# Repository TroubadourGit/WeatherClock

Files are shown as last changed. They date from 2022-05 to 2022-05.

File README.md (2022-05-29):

# 天气闹钟 (WeatherClock)

| 版本 | 修改日期  | 修改人 | 变更 |
| ---- | --- | --- | ---- |
| V1.0 | 2022.5.29 | Troubadour | |

---

## 主要功能

  1. 用户可以进行自行配网；
  2. WeatherClock 连上网络后会自动向互联网获取信息，获取的信息是：时间和天气预报；
  3. WeatherClock 带有一个显示屏， 显示界面共有三个：时间、当前天气、后天的天气预报，每5s切换一次界面。

---

## 使用说明

  1. 开机：拨动 WeatherClock 的开关即可开机， 开机亮蓝色指示灯。
  2. 配网：开机后第一件事情就是配网，刚开机时 WeatherClock 会自己开启一个wifi热点，用手机连上后会自动跳转到浏览器配网界面，在该界面为 WeatherClock 配网。配完网之后，等待 WeatherClock 加载即可。
  3. 充电：WeatherClock 自带一块800mh的锂电池，理论待机30小时以上。充电只需要手机充电器；注意，充电接口为Type-C接口。充电时亮起红色指示灯说明正在充电，充满电后红色指示灯熄灭。

***

## 文档说明

1. PCB+SCH：存放WeatherClock的PCB和原理图。
2. code：存放WeatherClock的代码。
3. 3DFile：存放3D外壳文件。
4. Other：存放开发以来一共购入的材料的excel文件。

---

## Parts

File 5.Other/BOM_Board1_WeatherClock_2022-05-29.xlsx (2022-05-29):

No. | Quantity | Device | Designator | Footprint | Supplier Part
1 | 1 | 0.1uF | C1 | C0805
2 | 1 | 0.1uF_C0805 | C2 | C0805
3 | 1 | 10uF | C3 | C0805
4 | 3 | 10uF_C0805 | C4,C5,C9 | C0805
5 | 1 | 68pF | C6 | C0805
6 | 1 | 22uF | C7 | C0805
7 | 1 | 22uF_C0805 | C8 | C0805
8 | 1 | ZH1.5_2P | J1 | CONN-TH_B2B-ZR-3.4-LF-SN | C163033
9 | 1 | L1008 | L1 | L0402 | C560042
10 | 1 | 红灯 | LED1 | LED0805_RED | C72037
11 | 1 | 蓝灯 | LED2 | LED0805_BLUE | C108412
12 | 1 | OLED-0.96-12864-IIC | M1 | OLED-0.96-12864-IIC_4PIN | ZJY096I0400WG11
13 | 1 | S8050 | Q1 | SOT-23-3_L2.9-W1.3-P1.90-LS2.4-BR | C2926165
14 | 1 | S8050_SOT-23-3_L2.9-W1.3-P1.90-LS2.4-BR | Q2 | SOT-23-3_L2.9-W1.3-P1.90-LS2.4-BR | C2926165
15 | 3 | 10k_R0805 | R1,R11,R12 | R0805
16 | 1 | 10k | R2 | R0805
17 | 1 | 4.7k | R3 | R0805
18 | 1 | 4.7k_R0805 | R4 | R0805
19 | 1 | 2k | R5 | R0805
20 | 1 | 1k | R6 | R0805
21 | 1 | 820k | R7 | R0805
22 | 1 | 143k | R8 | R0805
23 | 1 | 750k | R9 | R0805
24 | 1 | 1K_R0805 | R10 | R0805
25 | 1 | SK12D07VG6 | SW1 | SW-TH_SK12D07VG6 | C2681575
26 | 1 | ESP-01S_C503582 | U1 | WIFIM-TH_8P-L24.7-W14.4-P2.54 | C503582
27 | 1 | CH340C | U2 | SOP-16_L10.0-W3.9-P1.27-LS6.0-BL | C84681
28 | 1 | MP2155GQ-Z | U3 | QFN-10_L3.0-W3.0-P0.50-LS3.0-BL-EP | C110397
29 | 1 | PJ4054 | U4 | SOT-23-5_L3.0-W1.7-P0.95-LS2.8-TL | C440262
30 | 1 | KH-TYPE-C-16P | USB1 | USB-C-SMD_KH-TYPE-C-16P | C709357

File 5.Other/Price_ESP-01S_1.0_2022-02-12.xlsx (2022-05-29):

ID | 名称 | 标识符 | 封装 | 数量 | 单价 | 运费 | 小计 | 渠道 | 备注
 | V1.0 购入以下
1 | 0.1uF | C1,C2 | C0805 | 100 | 0.02 | 0 | 2 | 淘宝 | 深圳市裕泓科技有限公司
2 | 10uF | C3,C5 | C0805 | 100 | 0.02 | 0 | 2 | 淘宝 | 深圳市裕泓科技有限公司
3 | 红灯 | LED1 | LED0805_RED | 100 | 0.02 | 0 | 2 | 淘宝 | 深圳市裕泓科技有限公司
4 | 蓝灯 | LED2 | LED0805_BLUE | 100 | 0.02 | 0 | 2 | 淘宝 | 深圳市裕泓科技有限公司
5 | 10k | R1,R2 | R0805 | 100 | 0.02 | 0 | 2 | 淘宝 | 深圳市裕泓科技有限公司
6 | 4.7k | R3,R4 | R0805 | 100 | 0.02 | 0 | 2 | 淘宝 | 深圳市裕泓科技有限公司
7 | 1.2k | R5 | R0805 | 100 | 0.02 | 0 | 2 | 淘宝 | 深圳市裕泓科技有限公司
8 | 1k | R6,R8 | R0805 | 100 | 0.02 | 0 | 2 | 淘宝 | 深圳市裕泓科技有限公司
9 | OLED-0.96-12864-IIC | M1 | OLED-0.96-12864-IIC_4PIN | 3 | 10.8 | 0 | 32.4 | 淘宝 | 信泰微电子
10 | PJ4054 | U4 | SOT-23-5_L3.0-W1.7-P0.95-LS2.8-TL | 5 | 0.36 | 1.8 | 3.6 | 淘宝 | 酷米仕科技官方店
11 | ESP-01S_C503582 | U1 | WIFIM-TH_8P-L24.7-W14.4-P2.54 | 3 | 5.033333333 | 5 | 20.1 | 淘宝 | 深圳市轩特佳电子
12 | CH340C | U2 | SOP-16_L10.0-W3.9-P1.27-LS6.0-BL | 5 | 3.12 | 0 | 15.6 | 淘宝 | 深圳市优信电子
13 | 3.7V锂电池包 | BAT1 | 730mh-603040_ZH1.5-2P | 2 | 9.705 | 0 | 19.41 | 淘宝 | 深圳市绍能电子
14 | ZH1.5_2P | J1 | CONN-TH_B2B-ZR-3.4-LF-SN | 10 | 0.349 | 1.75 | 5.24 | 立创商城 | C163033
15 | SK12D07VG4 | SW1 | SW-TH_SK12D07VG4 | 50 | 0.12 | 1.75 | 7.75 | 立创商城 | C393937
16 | AMS1117-3.3_C369933 | U3 | SOT-223-4_L6.5-W3.5-P2.30-LS7.0-BR | 5 | 0.552 | 1.75 | 4.51 | 立创商城 | C369933
17 | MICROXNJ | USB1 | MICRO-USB-SMD_MICROXNJ | 10 | 0.285 | 1.75 | 4.6 | 立创商城 | C404969
 |  |  |  |  |  | 小结： | 129.21
 | V1.1 购入以下
18 | 68pF | C6 | C0805 | 50 | 0.04 | 0 | 2 | 淘宝 | 欧贝顿旗舰店
19 | 22uF | C7,C8 | C0805 | 20 | 0.1 | 0 | 2 | 淘宝 | 欧贝顿旗舰店
20 | 820k | R7 | R0805 | 100 | 0.026 | 0 | 2.6 | 淘宝 | 欧贝顿旗舰店
21 | 143k | R8 | R0805 | 100 | 0.03 | 0 | 3 | 淘宝 | 欧贝顿旗舰店
22 | 750k | R9 | R0805 | 100 | 0.026 | 0 | 2.6 | 淘宝 | 欧贝顿旗舰店
23 | 470Ω | R10 | R0805 | 100 | 0.026 | 0 | 2.6 | 淘宝 | 欧贝顿旗舰店
24 | MP2155GQ-Z | U3 | QFN-10_L3.0-W3.0-P0.50-LS3.0-BL-EP | 5 | 3 | 0 | 15 | 淘宝 | 深圳市裕泓科技有限公司
25 | KH-TYPE-C-16P | USB1 | USB-C-SMD_KH-TYPE-C-16P | 10 | 0.552 | 3.5 | 9.02 | 立创商城 | C709357
26 | 3.3uH | L1 | L0805 | 10 | 0.378 | 3.5 | 7.28 | 立创商城 | C162585
 |  |  |  |  |  | 小结： | 46.1
 | V1.5 购入以下
27 | ZH1.5mm端子线 |  |  | 5 | 1 |  | 5 | 淘宝 | 深圳市优信电子
28 | 3.7V锂电池包 | BAT1 | 1500mh-103040_ZH1.5-2P | 2 | 5.95 |  | 11.9 | 淘宝 | 雅格电池
29 | S8050 | Q1 | SOT-23-3_L2.9-W1.3-P1.90-LS2.4-BR | 100 | 0.03 |  | 3 | 淘宝 | 欧贝顿旗舰店
30 | S8550 | Q1 | SOT-23-3_L2.9-W1.3-P1.90-LS2.4-BR | 100 | 0.03 |  | 3 | 淘宝 | 欧贝顿旗舰店
31 | PJ4054 | U4 | SOT-23-5_L3.0-W1.7-P0.95-LS2.8-TL | 10 | 0.36 | 1.8 | 5.4 | 淘宝 | 酷米仕科技官方店
32 | MP2155GQ-Z | U3 | QFN-10_L3.0-W3.0-P0.50-LS3.0-BL-EP | 5 | 3 | 0 | 15 | 淘宝 | 深圳市裕泓科技有限公
33 | CH340C | U2 | SOP-16_L10.0-W3.9-P1.27-LS6.0-BL | 2 | 2.8 |  | 5.6 | 淘宝 | 深圳市瑞芯拓展电子商
34 | SK12D07VG6 | SW1 | SW-TH_SK12D07VG6 | 20 | 0.1085 |  | 2.17 | 立创商城 | C2681575
35 | 2k±1% | R5 | R0805 | 200 | 0.01535 |  | 3.07 | 立创商城 | C17604
36 | ZH1.5_2P | J1 | CONN-TH_B2B-ZR-3.4-LF-SN | 20 | 0.244 |  | 4.88 | 立创商城 | C158011
37 | KH-TYPE-C-16P | USB1 | USB-C-SMD_KH-TYPE-C-16P | 10 | 0.552 |  | 5.52 | 立创商城 | C709357
38 | 3.3uH | L1 | L0805 | 10 | 0.356 |  | 3.56 | 立创商城 | C162585
39 |  |  |  |  |  | 立创运费: | 7
40 | 圆孔排母镀金 |  | 2.54-1*40P | 2 | 1.785 |  | 3.57 | 淘宝 | 晶立弘泰旗舰店
41 | 单排母 2.54mm单排母座 |  | 2.54-1*20P | 10 | 0.278 |  | 2.78 | 淘宝 | WXRKDZ电子旗舰店
42 | 单排母 2.54mm单排母座 |  | 2.54-1*10P | 20 | 0.11 |  | 2.2 | 淘宝 | WXRKDZ电子旗舰店
43 | 单排母 2.54mm单排母座 |  | 2.54-1*4P | 20 | 0.1375 |  | 2.75 | 淘宝 | WXRKDZ电子旗舰店
44 | 六角铜柱 |  | M2*5+3 | 20 | 0.097 |  | 1.94 | 淘宝 | 固万基旗舰店
45 | 304不锈钢螺母六角螺帽 |  | M2 | 50 | 0.048 |  | 2.4 | 淘宝 | 恩鼎旗舰店
46 | 不锈钢沉头自攻钉螺丝 |  | M2*5 | 100 | 0.027 |  | 2.7 | 淘宝 | 恩鼎旗舰店
47 | 不锈钢沉头自攻钉螺丝 |  | M2*8 | 150 | 0.0266 |  | 3.99 | 淘宝 | 恩鼎旗舰店
48 | 3D打印外壳第一次 |  |  | 3 | 3.853333333 | 6.01 | 17.57 | 嘉立创 | 三维猴
49 | 3D打印外壳第二次 |  |  | 4 | 3.105 | 6.01 | 18.43 | 嘉立创 | 三维猴
50 | 3D打印外壳第三次 |  |  | 4 | 4.815 | 6.02 | 25.28 | 嘉立创 | 三维猴
51 | 4D打印外壳第四次 |  |  | 4 | 4.7025 | 6.02 | 24.83 | 嘉立创 | 三维猴
 |  |  |  |  |  | 小结： | 183.54
 |  |  |  |  |  | 总价： | 358.85

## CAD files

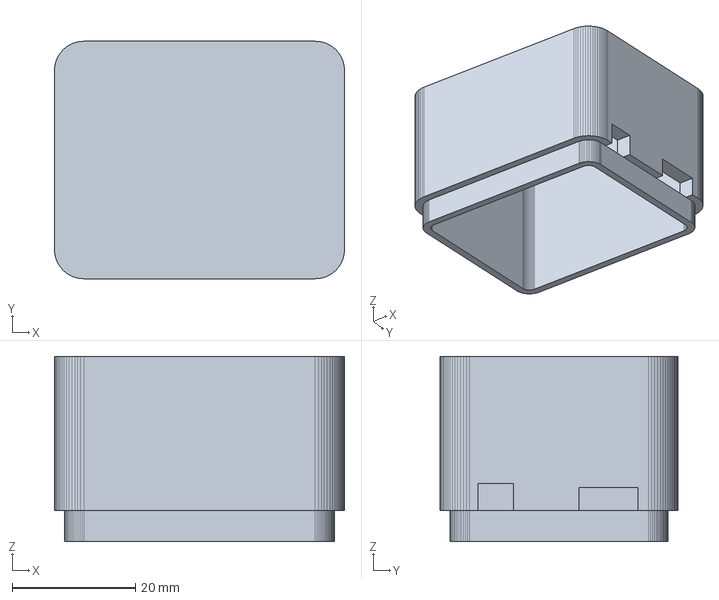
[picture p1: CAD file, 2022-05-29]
3.3DFile/3DShell_PCB_ESP-01S_T.step
47.0 x 38.5 x 30.0 mm

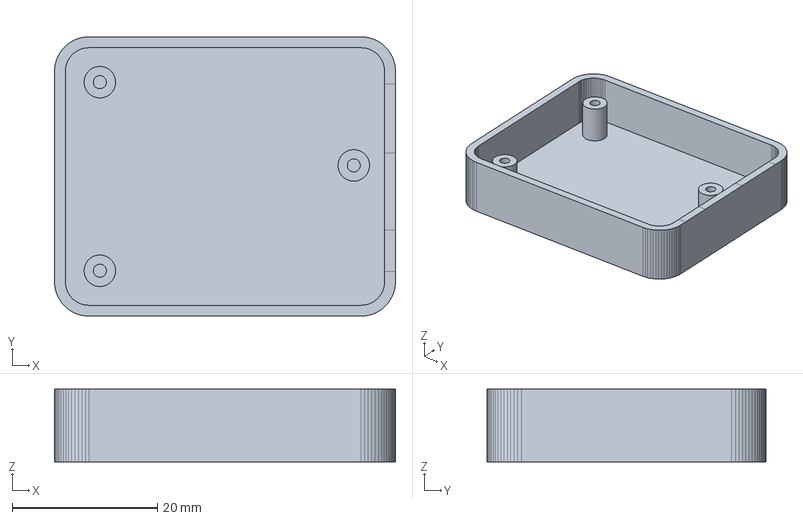
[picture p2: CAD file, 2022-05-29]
3.3DFile/3DShell_PCB_ESP-01S_B.step
47.0 x 38.5 x 10.0 mm

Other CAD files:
3.3DFile/3dshell_pcb_esp-01s_b.stl
3.3DFile/3dshell_pcb_esp-01s_t.stl

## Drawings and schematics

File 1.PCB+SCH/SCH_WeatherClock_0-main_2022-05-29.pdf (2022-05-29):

电平转换 | MUC

# 自动下载电路

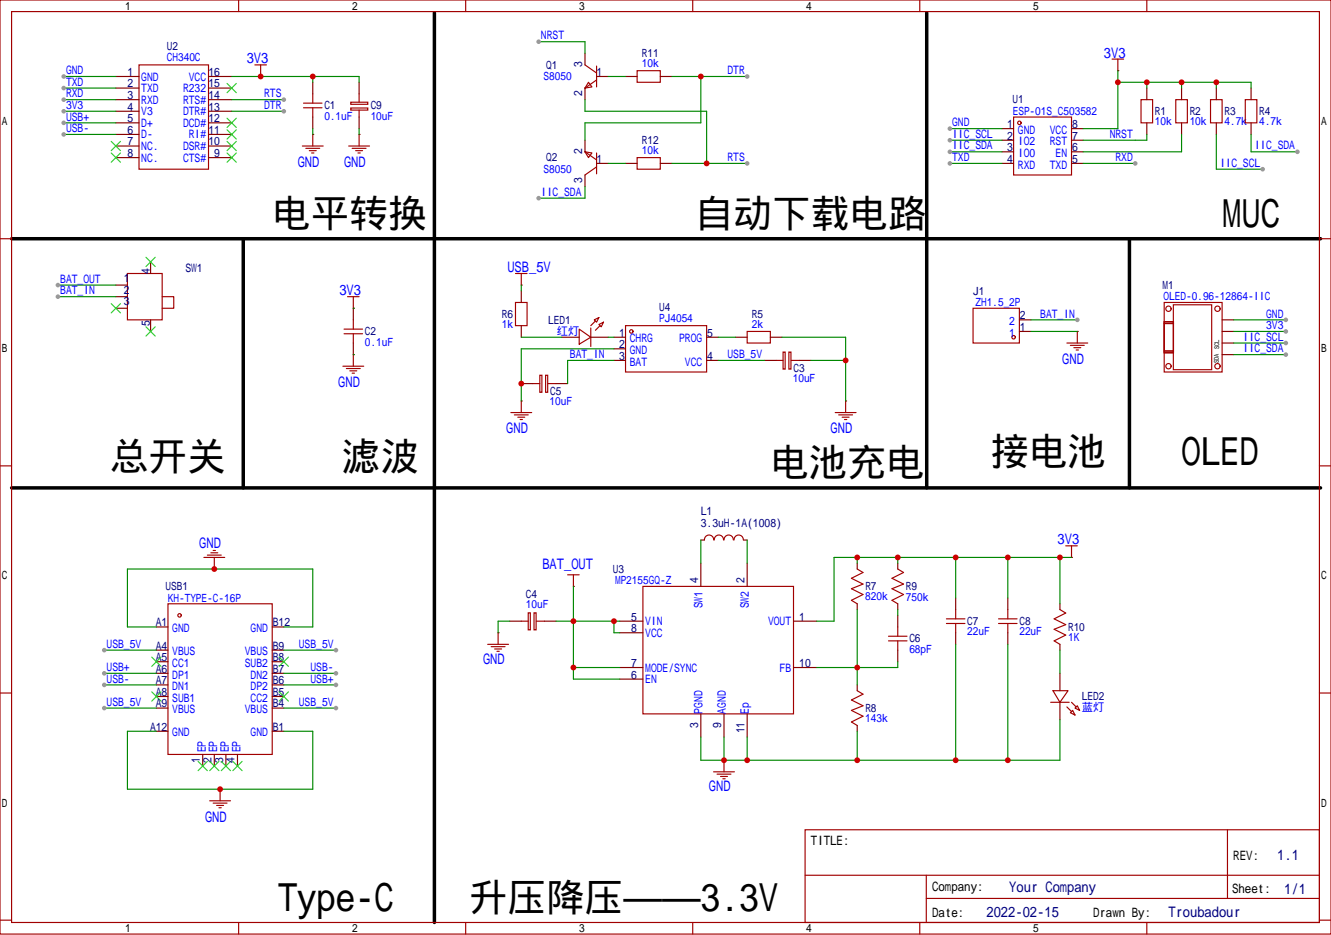
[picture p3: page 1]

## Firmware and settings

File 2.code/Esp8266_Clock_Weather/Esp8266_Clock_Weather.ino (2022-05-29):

#include <Arduino.h>
#include <ESP8266WiFi.h>
#include <ESP8266HTTPClient.h>

#include <DNSServer.h>//密码直连将其三个库注释
#include <ESP8266WebServer.h>
#include <CustomWiFiManager.h>

#include <time.h>                       
#include <sys/time.h>                  
#include <coredecls.h>      


//#include "SH1106Wire.h"   //1.3寸用这个
#include "SSD1306Wire.h"    //0.96寸用这个
#include "OLEDDisplayUi.h"
#include "HeFeng.h"
#include "WeatherStationFonts.h"
#include "WeatherStationImages.h"

/***************************
   Begin Settings
 **************************/
/*  使用Web配网请注释本宏即可  */
// #define  WifiPassConnect

const char* WIFI_SSID = "Mr.Qin";  //填写你的WIFI名称及密码
const char* WIFI_PWD = "qin666666";

const char* BILIBILIID = "104521763";  //填写你的B站账号

//由于太多人使用我的秘钥，导致获取次数超额，所以不提供秘钥了，大家可以到https:// dev.heweather.com/获取免费的
const char* HEFENG_KEY = "243a741836da45739cd3130422ca9b55"; // 填写你的和风天气秘钥
const char* HEFENG_LOCATION = "CN101280608";  // 填写你的城市ID,可到https://where.heweather.com/index.html查询
// const char* HEFENG_LOCATION = "auto_ip";         // 自动IP定位

#define TZ              8      // 中国时区为8
#define DST_MN          0      // 默认为0

const int UPDATE_INTERVAL_SECS = 5 * 60; // 5分钟更新一次天气
const int UPDATE_CURR_INTERVAL_SECS = 2 * 59; // 2分钟更新一次粉丝数

const int I2C_DISPLAY_ADDRESS = 0x3c;  //I2c地址默认
#if defined(ESP8266)
const int SDA_PIN = 0;  //引脚连接
const int SDC_PIN = 2;  //
#endif


const String WDAY_NAMES[] = {"Sun", "Mon", "Tue", "Wed", "Thu", "Fri", "Sat"};  //星期
const String MONTH_NAMES[] = {"Jan", "Feb", "Mar", "Apr", "May", "Jun", "Jul", "Aug", "Sep", "Oct", "Nov", "Dec"};  //月份

// web配网页面自定义我的图标请随便使用一个图片转base64工具转换https://oktools.net/image2base64, 64*64--JPGE格式
   const char Icon[] PROGMEM = "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";

/***************************
   End Settings
 **************************/
 
//SH1106Wire     display(I2C_DISPLAY_ADDRESS, SDA_PIN, SDC_PIN);   // 1.3寸用这个
SSD1306Wire     display(I2C_DISPLAY_ADDRESS, SDA_PIN, SDC_PIN);   // 0.96寸用这个
OLEDDisplayUi   ui( &display );

HeFengCurrentData currentWeather; //实例化对象
HeFengForeData foreWeather[3];
HeFeng HeFengClient;

#define TZ_MN           ((TZ)*60)   //时间换算
#define TZ_SEC          ((TZ)*3600)
#define DST_SEC         ((DST_MN)*60)

time_t now; //实例化时间

bool readyForWeatherUpdate = false; // 天气更新标志
bool first = true;  //首次更新标志
long timeSinceLastWUpdate = 0;    //上次更新后的时间
long timeSinceLastCurrUpdate = 0;   //上次天气更新后的时间

String fans = "-1"; //粉丝数

void drawProgress(OLEDDisplay *display, int percentage, String label);   //提前声明函数
void updateData(OLEDDisplay *display);
void updateDatas(OLEDDisplay *display);
void drawDateTime(OLEDDisplay *display, OLEDDisplayUiState* state, int16_t x, int16_t y);
void drawCurrentWeather(OLEDDisplay *display, OLEDDisplayUiState* state, int16_t x, int16_t y);
void drawForecast(OLEDDisplay *display, OLEDDisplayUiState* state, int16_t x, int16_t y);
void drawForecastDetails(OLEDDisplay *display, int x, int y, int dayIndex);
void drawHeaderOverlay(OLEDDisplay *display, OLEDDisplayUiState* state);
void setReadyForWeatherUpdate();

//添加框架
//此数组保留指向所有帧的函数指针
//框架是从右向左滑动的单个视图
FrameCallback frames[] = { drawDateTime, drawCurrentWeather, drawForecast };
//页面数量
int numberOfFrames = 3;

OverlayCallback overlays[] = { drawHeaderOverlay }; //覆盖回调函数
int numberOfOverlays = 1;  //覆盖数

void setup() {
  Serial.begin(115200);
  Serial.println();
  Serial.println();

  // 屏幕初始化
  display.init();
  display.clear();
  display.display();

  display.flipScreenVertically(); //屏幕翻转
  display.setContrast(255); //屏幕亮度

#ifdef WifiPassConnect
  // 用固定密码连接，Web配网请注释
  wificonnect();
#else
  //Web配网，密码直连请注释
  webconnect();
#endif


  ui.setTargetFPS(30);  //刷新频率

  ui.setActiveSymbol(activeSymbole); //设置活动符号
  ui.setInactiveSymbol(inactiveSymbole); //设置非活动符号

  // 符号位置
  // 你可以把这个改成TOP, LEFT, BOTTOM, RIGHT
  ui.setIndicatorPosition(BOTTOM);

  // 定义第一帧在栏中的位置
  ui.setIndicatorDirection(LEFT_RIGHT);

  // 屏幕切换方向
  // 您可以更改使用的屏幕切换方向 SLIDE_LEFT, SLIDE_RIGHT, SLIDE_TOP, SLIDE_DOWN
  ui.setFrameAnimation(SLIDE_LEFT);

  ui.setFrames(frames, numberOfFrames); // 设置框架
  ui.setTimePerFrame(5000); //设置切换时间
  
  ui.setOverlays(overlays, numberOfOverlays); //设置覆盖

  // UI负责初始化显示
  ui.init();
  display.flipScreenVertically(); //屏幕反转

  configTime(TZ_SEC, DST_SEC, "ntp.ntsc.ac.cn", "ntp1.aliyun.com"); //ntp获取时间，你也可用其他"pool.ntp.org","0.cn.pool.ntp.org","1.cn.pool.ntp.org","ntp1.aliyun.com"
  delay(200);

}

void loop() {
  if (first) {  //首次加载
    updateDatas(&display);
    first = false;
  }
  if (millis() - timeSinceLastWUpdate > (1000L * UPDATE_INTERVAL_SECS)) { //屏幕刷新
    setReadyForWeatherUpdate();
    timeSinceLastWUpdate = millis();
  }
  if (millis() - timeSinceLastCurrUpdate > (1000L * UPDATE_CURR_INTERVAL_SECS)) { //粉丝数更新
    HeFengClient.fans(&currentWeather, BILIBILIID);
    fans = String(currentWeather.follower);
    timeSinceLastCurrUpdate = millis();
  }

  if (readyForWeatherUpdate && ui.getUiState()->frameState == FIXED) { //天气更新
    updateData(&display);
  }

  int remainingTimeBudget = ui.update(); //剩余时间预算

  if (remainingTimeBudget > 0) {
    //你可以在这里工作如果你低于你的时间预算。
    delay(remainingTimeBudget);
  }
  
}

#ifdef WifiPassConnect
void wificonnect() {  //WIFI密码连接，Web配网请注释
  WiFi.begin(WIFI_SSID, WIFI_PWD);
  while (WiFi.status() != WL_CONNECTED) {
    Serial.print('.');
    delay(80);
    display.clear();
    display.drawXbm(34, 0, bili_Logo_width, bili_Logo_height, bili_Logo_5);
    display.display();
    delay(80);
    display.clear();
    display.drawXbm(34, 0, bili_Logo_width, bili_Logo_height, bili_Logo_6);
    display.display();
    delay(80);
    display.clear();
    display.drawXbm(34, 0, bili_Logo_width, bili_Logo_height, bili_Logo_7);
    display.display();
    delay(80);
    display.clear();
    display.drawXbm(34, 0, bili_Logo_width, bili_Logo_height, bili_Logo_8);
    display.display();
    delay(80);
    display.clear();
    display.drawXbm(34, 0, bili_Logo_width, bili_Logo_height, bili_Logo_1);
    display.display();
    delay(80);
    display.clear();
    display.drawXbm(34, 0, bili_Logo_width, bili_Logo_height, bili_Logo_2);
    display.display();
    delay(80);
    display.clear();
    display.drawXbm(34, 0, bili_Logo_width, bili_Logo_height, bili_Logo_3);
    display.display();
    delay(80);
    display.clear();
    display.drawXbm(34, 0, bili_Logo_width, bili_Logo_height, bili_Logo_4);
    display.display();
  }
  Serial.println("");
  delay(500);
}
#else
void webconnect() {  ////Web配网，密码直连将其注释
  display.clear();
  display.drawXbm(0, 0, 128, 64, bilibili); //显示哔哩哔哩
  display.display();

  WiFiManager wifiManager;  //实例化WiFiManager
  wifiManager.setDebugOutput(false); //关闭Debug
  //wifiManager.setConnectTimeout(10); //设置超时
  wifiManager.setHeadImgBase64(FPSTR(Icon)); //设置图标
  wifiManager.setPageTitle("欢迎来到游吟诗人的WiFi配置页");  //设置页标题

  // if (!wifiManager.autoConnect("XiaoKai-IOT-Display")) {  //AP模式
  if (!wifiManager.autoConnect("Troubadour_Config")) {  //AP模式
    Serial.println("连接失败并超时");
    //重新设置并再试一次，或者让它进入深度睡眠状态
    ESP.restart();
    delay(1000);
  }
  Serial.println("connected...^_^");
  yield();
}
#endif

void drawProgress(OLEDDisplay *display, int percentage, String label) {    //绘制进度
  display->clear();
  display->setTextAlignment(TEXT_ALIGN_CENTER);
  display->setFont(ArialMT_Plain_10);
  display->drawString(64, 10, label);
  display->drawProgressBar(2, 28, 124, 10, percentage);
  display->display();
}

void updateData(OLEDDisplay *display) {  //天气更新
  HeFengClient.doUpdateCurr(&currentWeather, HEFENG_KEY, HEFENG_LOCATION);
  HeFengClient.doUpdateFore(foreWeather, HEFENG_KEY, HEFENG_LOCATION);
  readyForWeatherUpdate = false;
}

void updateDatas(OLEDDisplay *display) {  //首次天气更新
  drawProgress(display, 0, "Updating fansnumb...");
  HeFengClient.fans(&currentWeather, BILIBILIID);
  fans = String(currentWeather.follower);
  
  drawProgress(display, 33, "Updating weather...");
  HeFengClient.doUpdateCurr(&currentWeather, HEFENG_KEY, HEFENG_LOCATION);
  
  drawProgress(display, 66, "Updating forecasts...");
  HeFengClient.doUpdateFore(foreWeather, HEFENG_KEY, HEFENG_LOCATION);
  
  readyForWeatherUpdate = false;
  drawProgress(display, 100, "Done...");
  delay(200);
  
}

void drawDateTime(OLEDDisplay *display, OLEDDisplayUiState* state, int16_t x, int16_t y) {  //显示时间
  now = time(nullptr);
  struct tm* timeInfo;
  timeInfo = localtime(&now);
  char buff[16];

  display->setTextAlignment(TEXT_ALIGN_CENTER);
  display->setFont(ArialMT_Plain_16);
  String date = WDAY_NAMES[timeInfo->tm_wday];

  sprintf_P(buff, PSTR("%04d-%02d-%02d  %s"), timeInfo->tm_year + 1900, timeInfo->tm_mon + 1, timeInfo->tm_mday, WDAY_NAMES[timeInfo->tm_wday].c_str());
  display->drawString(64 + x, 5 + y, String(buff));
  display->setFont(ArialMT_Plain_24);

  sprintf_P(buff, PSTR("%02d:%02d:%02d"), timeInfo->tm_hour, timeInfo->tm_min, timeInfo->tm_sec);
  display->drawString(64 + x, 22 + y, String(buff));
  display->setTextAlignment(TEXT_ALIGN_LEFT);
}

void drawCurrentWeather(OLEDDisplay *display, OLEDDisplayUiState* state, int16_t x, int16_t y) {  //显示天气
  display->setFont(ArialMT_Plain_10);
  display->setTextAlignment(TEXT_ALIGN_CENTER);
  display->drawString(64 + x, 38 + y, currentWeather.cond_txt + "    |   Wind: " + currentWeather.wind_sc + "  ");

  display->setFont(ArialMT_Plain_24);
  display->setTextAlignment(TEXT_ALIGN_LEFT);
  String temp = currentWeather.tmp + "°C" ;
  display->drawString(60 + x, 3 + y, temp);
  display->setFont(ArialMT_Plain_10);
  display->drawString(62 + x, 26 + y, currentWeather.fl + "°C | " + currentWeather.hum + "%");
  display->setFont(Meteocons_Plain_36);
  display->setTextAlignment(TEXT_ALIGN_CENTER);
  display->drawString(32 + x, 0 + y, currentWeather.iconMeteoCon);
}

void drawForecast(OLEDDisplay *display, OLEDDisplayUiState* state, int16_t x, int16_t y) {  //天气预报
  drawForecastDetails(display, x, y, 0);
  drawForecastDetails(display, x + 44, y, 1);
  drawForecastDetails(display, x + 88, y, 2);
}

void drawForecastDetails(OLEDDisplay *display, int x, int y, int dayIndex) {  //天气预报

  display->setTextAlignment(TEXT_ALIGN_CENTER);
  display->setFont(ArialMT_Plain_10);
  display->drawString(x + 20, y, foreWeather[dayIndex].datestr);
  display->setFont(Meteocons_Plain_21);
  display->drawString(x + 20, y + 12, foreWeather[dayIndex].iconMeteoCon);

  String temp = foreWeather[dayIndex].tmp_max + " | " + foreWeather[dayIndex].tmp_min;
  display->setFont(ArialMT_Plain_10);
  display->drawString(x + 20, y + 34, temp);
  display->setTextAlignment(TEXT_ALIGN_LEFT);
}

void drawHeaderOverlay(OLEDDisplay *display, OLEDDisplayUiState* state) {   //绘图页眉覆盖
  now = time(nullptr);
  struct tm* timeInfo;
  timeInfo = localtime(&now);
  char buff[14];
  sprintf_P(buff, PSTR("%02d:%02d"), timeInfo->tm_hour, timeInfo->tm_min);

  display->setColor(WHITE);
  display->setFont(ArialMT_Plain_10);
  display->setTextAlignment(TEXT_ALIGN_LEFT);
  display->drawString(6, 54, String(buff));
  display->setTextAlignment(TEXT_ALIGN_RIGHT);
  String temp = fans;
  display->drawString(122, 54, temp);
  display->drawHorizontalLine(0, 52, 128);
}

void setReadyForWeatherUpdate() {  //为天气更新做好准备
  Serial.println("Setting readyForUpdate to true");
  readyForWeatherUpdate = true;
}

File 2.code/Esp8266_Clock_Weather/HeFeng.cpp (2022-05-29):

#include <ESP8266WiFi.h>
#include <ESP8266HTTPClient.h>
#include <WiFiClientSecureBearSSL.h>
#include "HeFeng.h"

HeFeng::HeFeng() {
}

void HeFeng::fans(HeFengCurrentData *data, String id) {  //获取粉丝数
  std::unique_ptr<BearSSL::WiFiClientSecure>client(new BearSSL::WiFiClientSecure);
  client->setInsecure();
  HTTPClient https;
  String url = "https://api.bilibili.com/x/relation/stat?vmid=" + id;
  Serial.print("[HTTPS] begin...bilibili\n");
  if (https.begin(*client, url)) {  // HTTPS
    // start connection and send HTTP header
    int httpCode = https.GET();
    // httpCode will be negative on error
    if (httpCode > 0) {
      // HTTP header has been send and Server response header has been handled
      Serial.printf("[HTTPS] GET... code: %d\n", httpCode);

      if (httpCode == HTTP_CODE_OK || httpCode == HTTP_CODE_MOVED_PERMANENTLY) {
        String payload = https.getString();
        Serial.println(payload);
        DynamicJsonDocument  jsonBuffer(2048);
        deserializeJson(jsonBuffer, payload);
        JsonObject root = jsonBuffer.as<JsonObject>();

        String follower = root["data"]["follower"];
        data->follower = follower;
      }
    } else {
      Serial.printf("[HTTPS] GET... failed, error: %s\n", https.errorToString(httpCode).c_str());
      data->follower = "-1";
    }

    https.end();
  } else {
    Serial.printf("[HTTPS] Unable to connect\n");
    data->follower = "-1";
  }
}


// 使用自动识别地址时，定义变量保存识别到的城市ID给天气预报用
String Save_City_ID;
void HeFeng::doUpdateCurr(HeFengCurrentData *data, String key, String location) {  //获取天气

  std::unique_ptr<BearSSL::WiFiClientSecure>client(new BearSSL::WiFiClientSecure);
  client->setInsecure();
  HTTPClient https;
  String url = "https://free-api.heweather.net/s6/weather/now?lang=en&location=" + location + "&key=" + key;
  Serial.print("[HTTPS] begin...now\n");
  if (https.begin(*client, url)) {  // HTTPS
    // start connection and send HTTP header
    int httpCode = https.GET();
    // httpCode will be negative on error
    if (httpCode > 0) {
      // HTTP header has been send and Server response header has been handled
      Serial.printf("[HTTPS] GET... code: %d\n", httpCode);

      if (httpCode == HTTP_CODE_OK || httpCode == HTTP_CODE_MOVED_PERMANENTLY) {
        String payload = https.getString();
        Serial.println(payload);
        DynamicJsonDocument  jsonBuffer(2048);
        deserializeJson(jsonBuffer, payload);
        JsonObject root = jsonBuffer.as<JsonObject>();

        String tmp = root["HeWeather6"][0]["now"]["tmp"];
        data->tmp = tmp;
        String fl = root["HeWeather6"][0]["now"]["fl"];
        data->fl = fl;
        String hum = root["HeWeather6"][0]["now"]["hum"];
        data->hum = hum;
        String wind_sc = root["HeWeather6"][0]["now"]["wind_sc"];
        data->wind_sc = wind_sc;
        String cond_code = root["HeWeather6"][0]["now"]["cond_code"];
        String meteoconIcon = getMeteoconIcon(cond_code);
        String cond_txt = root["HeWeather6"][0]["now"]["cond_txt"];
        data->cond_txt = cond_txt;
        data->iconMeteoCon = meteoconIcon;
    
        Save_City_ID = root["HeWeather6"][0]["basic"]["cid"].as<String>();
      }
    } else {
      Serial.printf("[HTTPS] GET... failed, error: %s\n", https.errorToString(httpCode).c_str());
      data->tmp = "-1";
      data->fl = "-1";
      data->hum = "-1";
      data->wind_sc = "-1";
      data->cond_txt = "no network";
      data->iconMeteoCon = ")";
    }

    https.end();
  } else {
    Serial.printf("[HTTPS] Unable to connect\n");
    data->tmp = "-1";
    data->fl = "-1";
    data->hum = "-1";
    data->wind_sc = "-1";
    data->cond_txt = "no network";
    data->iconMeteoCon = ")";
  }

}

void HeFeng::doUpdateFore(HeFengForeData *data, String key, String location) {  //获取预报

  std::unique_ptr<BearSSL::WiFiClientSecure>client(new BearSSL::WiFiClientSecure);
  client->setInsecure();
  HTTPClient https;

  location = Save_City_ID;
  
  String url = "https://devapi.qweather.com/v7/weather/3d?lang=en&gzip=n&location=" + location + "&key=" + key;
  Serial.print("[HTTPS] begin...forecast\n");
  if (https.begin(*client, url)) {  // HTTPS
    // start connection and send HTTP header
    int httpCode = https.GET();
    // httpCode will be negative on error
    if (httpCode > 0) {
      // HTTP header has been send and Server response header has been handled
      Serial.printf("[HTTPS] GET... code: %d\n", httpCode);

      if (httpCode == HTTP_CODE_OK || httpCode == HTTP_CODE_MOVED_PERMANENTLY) {
        String payload = https.getString();
        Serial.println(payload);
        DynamicJsonDocument  jsonBuffer(4096);
        deserializeJson(jsonBuffer, payload);
        JsonObject root = jsonBuffer.as<JsonObject>();
        int i;
        for (i = 0; i < 3; i++) {
          String tmp_min = root["daily"][i]["tempMin"];
          data[i].tmp_min = tmp_min;
          String tmp_max = root["daily"][i]["tempMax"];
          data[i].tmp_max = tmp_max;
          String datestr = root["daily"][i]["fxDate"];
          data[i].datestr = datestr.substring(5, datestr.length());
          String cond_code = root["daily"][i]["iconDay"];
          String meteoconIcon = getMeteoconIcon(cond_code);
          data[i].iconMeteoCon = meteoconIcon;
        }
      }
    } else {
      Serial.printf("[HTTPS] GET... failed, error: %s\n", https.errorToString(httpCode).c_str());
      int i;
      for (i = 0; i < 3; i++) {
        data[i].tmp_min = "-1";
        data[i].tmp_max = "-1";
        data[i].datestr = "N/A";
        data[i].iconMeteoCon = ")";
      }
    }
    https.end();
  } else {
    Serial.printf("[HTTPS] Unable to connect\n");
    int i;
    for (i = 0; i < 3; i++) {
      data[i].tmp_min = "-1";
      data[i].tmp_max = "-1";
      data[i].datestr = "N/A";
      data[i].iconMeteoCon = ")";
    }
  }

}
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

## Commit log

2022-05-29 V1.0版本提交
    [1_main.schdoc, 3DShell_PCB_ESP-01S_B.step, 3DShell_PCB_ESP-01S_T.step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]
2022-05-29 添加了项目说明
2022-05-29 整理文件Tree
    [1_main.schdoc, 3DShell_PCB_ESP-01S_B.step, 3DShell_PCB_ESP-01S_T.step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]
2022-05-29 修改说明
2022-05-29 添加了Datasheet
    [BOM_Board1_WeatherClock_2022-05-29.xlsx, Price_ESP-01S_1.0_2022-02-12.xlsx]
